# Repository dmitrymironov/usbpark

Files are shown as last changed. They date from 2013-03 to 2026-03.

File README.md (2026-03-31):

# USBPark / Parktronic

Legacy USB parking-assist software + PCB design files for a real shipped product.

This project was originally a commercial product sold to **a few hundred customers**.  
It is now released publicly to support existing customer installations, maintenance, and long-term serviceability.

Initial project funding was provided by Petroff Air, a luxury business-jet operator, which sought customization and updates for its Q8 fleet using custom embedded car computers.

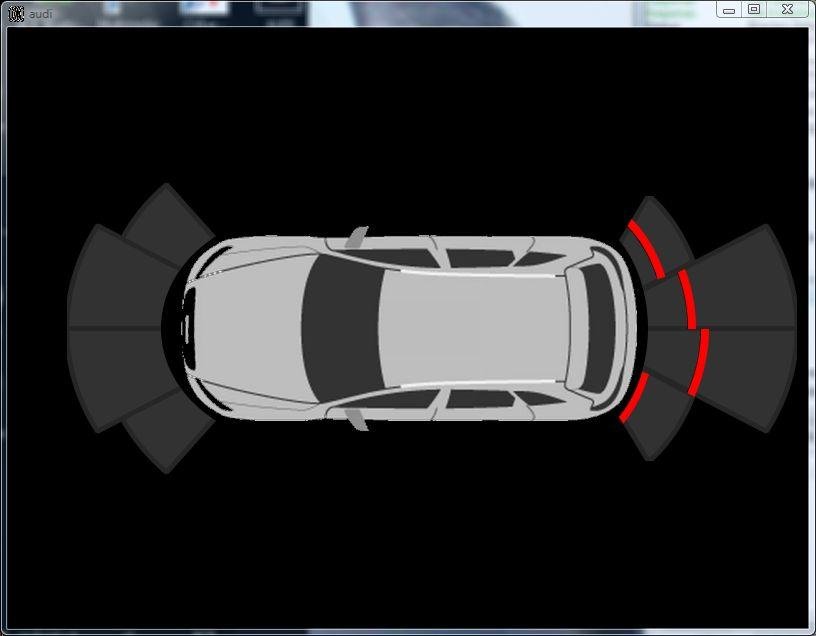
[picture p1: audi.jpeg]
USBPark demo (Audi)


## At a glance

- Desktop parking-assist software (`parktronic` and `audi`) built with Qt/C++.
- Hardware design files in Eagle format (`.sch`, `.brd`) in [`pcb/`](pcb/).
- PIC18 firmware source is included in [`firmware/`](firmware/).
- PIC18F-based controller design (PIC18F2550 appears in the v18 schematic/board design).
- Firmware update flow is integrated in the desktop app stack.

## Hardware

The latest schematic preview is included below:

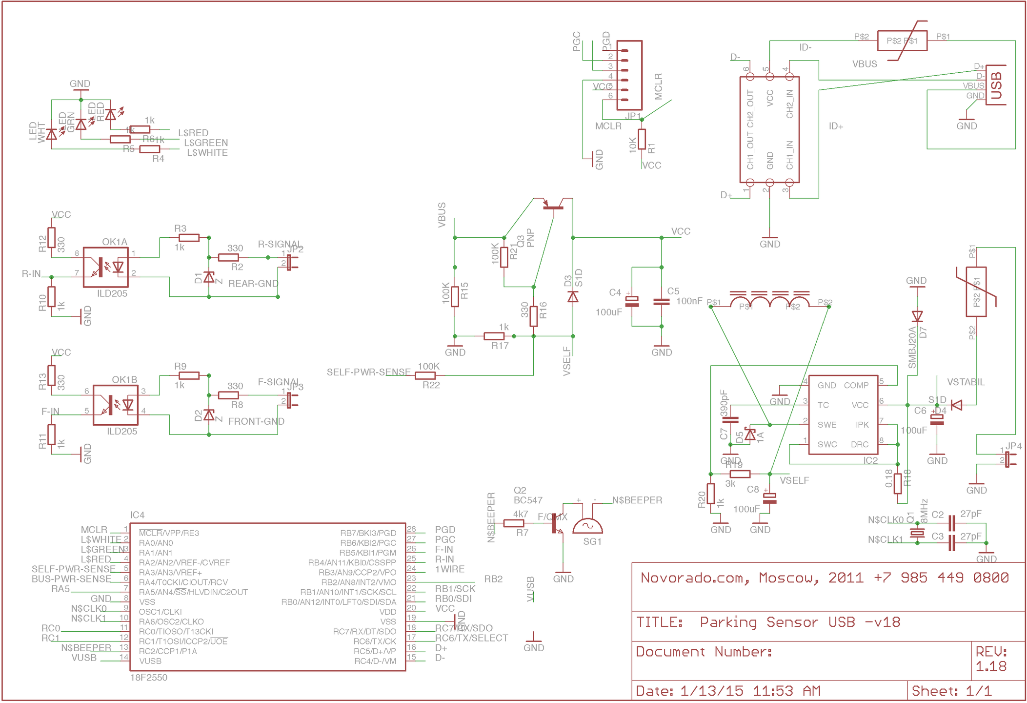
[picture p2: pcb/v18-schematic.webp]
Parking Sensor USB v18 schematic


Available PCB design assets:

- `pcb/Parking Sensor USB -v18.sch`
- `pcb/Parking Sensor USB -v18.brd`
- `pcb/Parking Sensor USB -v17b.sch`
- `pcb/Parking Sensor USB -v17b.brd`
- `pcb/v18-schematic.webp`

## Production and DIY artifacts

These files capture both ends of the hardware lifecycle: final production output and practical home-lab support tooling.

<table>
  <tr>
    <td align="center" width="50%">
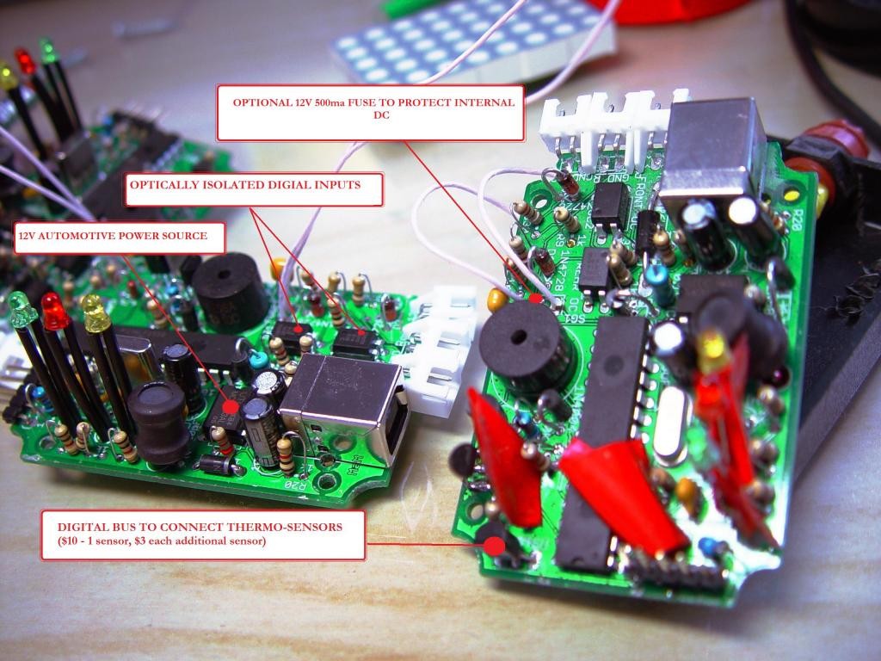
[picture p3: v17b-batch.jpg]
v17b production PCB batch
      
      <br />
      <em>v17b production batch: last commercially manufactured board run.</em>
    </td>
    <td align="center" width="50%">
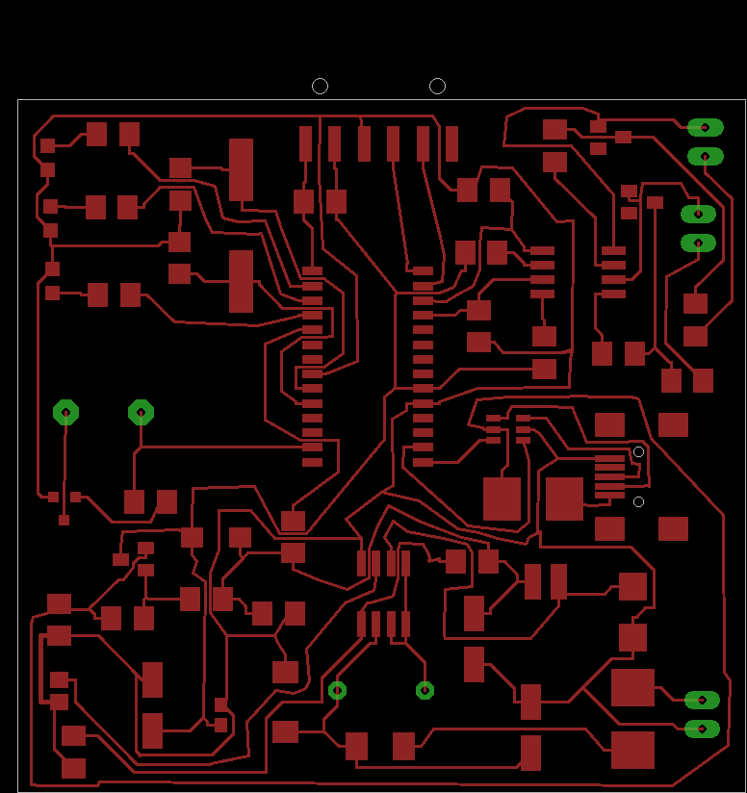
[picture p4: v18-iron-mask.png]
v18 iron mask for DIY single-metal PCB
      
      <br />
      <em>v18 iron mask: single-metal DIY transfer mask for home ironing workflow.</em>
    </td>
  </tr>
</table>

## Software components

### `parktronic/`

Main desktop application and diagnostics/configuration UI.

- Qt project: `parktronic/parktronic.pro`
- GUI tabs for diagnostics, firmware update, sounds, webcam, and settings
- Firmware resources referenced by the build (`hex/firmware.qrc`)
- Platform-specific entry points (`linux.cpp`, `win32.cpp`)

### `audi/`

Alternate/variant desktop UI package for the same product family.

- Qt project: `audi/audi.pro`
- Vehicle-oriented UI assets and sound notifications

### `firmware/`

PIC18 USB firmware source for the controller device.

- Main firmware entrypoint: `firmware/main.c`
- USB stack integration: `firmware/usb_device.c`, `firmware/usb_function_generic.c`, `firmware/usb_descriptors.c`, `firmware/usb_config.h`
- Version metadata: `firmware/version.h` (`VERSION_STRING "2.0.3"`)
- Linker scripts for PIC18F2550 variants:
  - `firmware/18F2550_NO_BOOTLOADER.lkr`
  - `firmware/rm18f2550_HID_Bootload.lkr`
- Protocol/sensor support files include I2C and DS1820 helpers plus line-decoding logic (`challenger26.*`, `i2c.*`, `ds1820.h`)

## PIC18F firmware context

This project includes a PIC18F USB-controller hardware design and host-side firmware update integration:

- Schematic/board reference to PIC18F2550 in `pcb/Parking Sensor USB -v18.sch` and `.brd`
- Host software contains firmware version/update handling paths
- Firmware source tree now included directly under `firmware/`
- Firmware code references legacy Microchip USB stack/C18 toolchain headers and bootloader settings (`../Bootloader/src/settings.h`)

## Build notes (legacy)

This is a legacy codebase (Qt4-era project files and platform-specific dependencies).

Typical flow:

```bash
cd parktronic
qmake parktronic.pro
make
```

and similarly for:

```bash
cd audi
qmake audi.pro
make
```

Notes:

- The original environment references external/internal Novorado libraries and SDK paths.
- You may need to adapt include/library paths before successful local builds.
- Firmware sources are legacy PIC18/Microchip C18-era code and may require restoring the original Microchip USB stack layout/toolchain paths to build as-is.

## Why this repo is public

The code and hardware design are published to keep deployed units supportable for existing users:

- preserve serviceability
- enable repairs and compatibility work
- allow community maintenance of legacy installations

## Repository layout

```text
usbpark-code/
├── audi/         # Variant desktop app (Qt/C++)
├── firmware/     # PIC18F2550 USB firmware source
├── parktronic/   # Main desktop app + diagnostics + firmware update UI
├── pcb/          # Eagle schematic/board files + schematic image
├── v17b-batch.jpg
├── v18-iron-mask.png
└── audi.jpeg     # Demo product image
```

## License and reuse

- `pcb/LICENSE` currently contains an MIT license text for PCB artifacts.
- Project history: originally commercial; now made public to support the installed base.
- If you need strict legal classification for reuse (public domain vs MIT-only subsets), document it explicitly for your distribution before shipping derivatives.

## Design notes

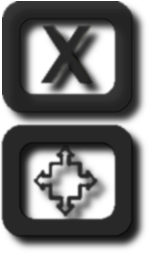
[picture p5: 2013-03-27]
audi/images/bsdark.png

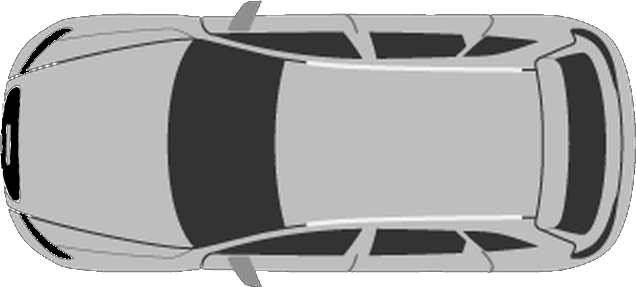
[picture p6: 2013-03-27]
audi/images/audi.png

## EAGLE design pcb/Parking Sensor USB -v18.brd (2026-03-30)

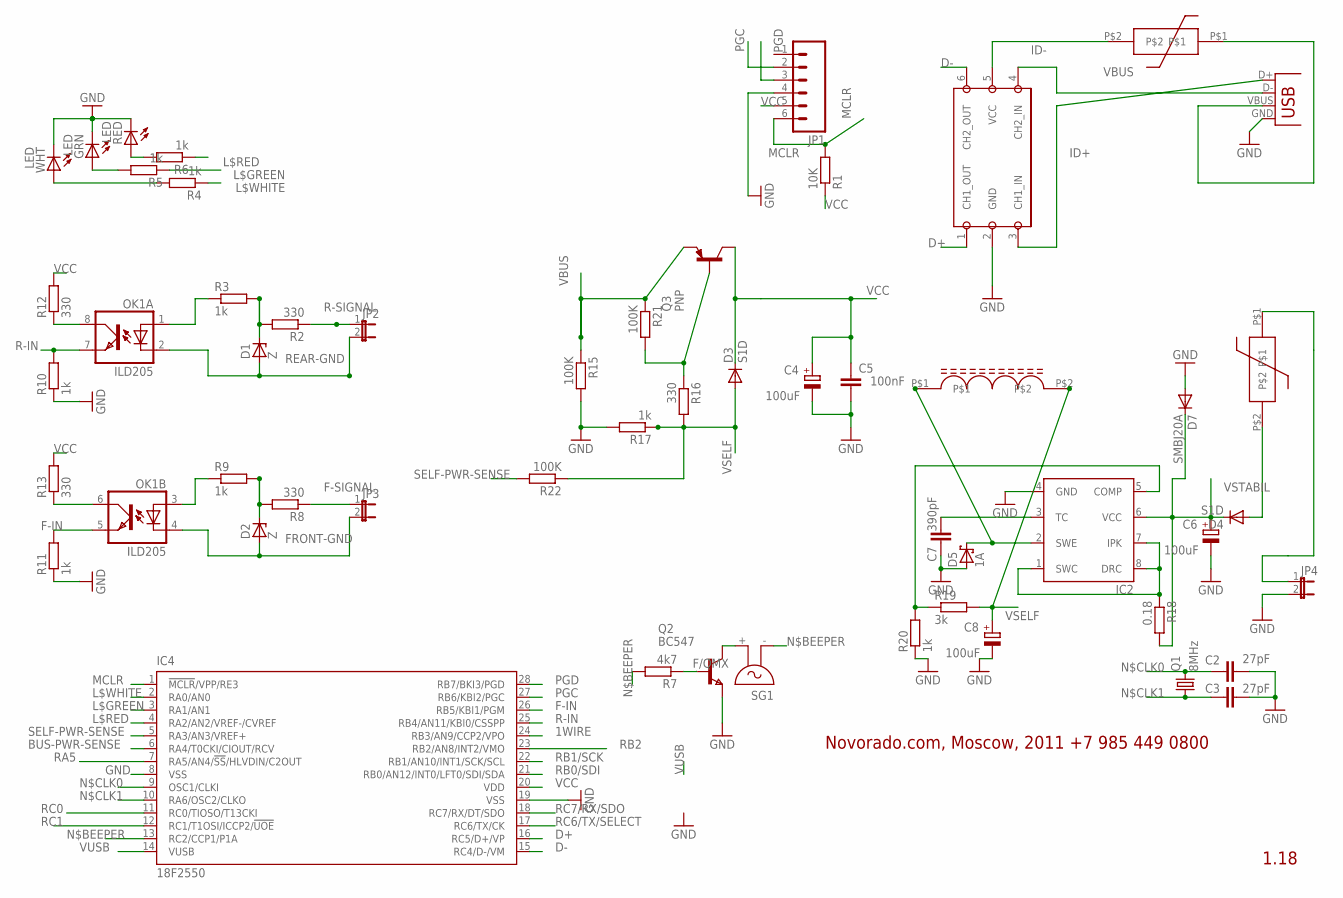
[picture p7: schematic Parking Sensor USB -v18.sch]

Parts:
C2, C3: 27pF; C1206
C4, C6, C8: 100uF; 153CLV-0505
C5: 100nF; C0603
C7: 390pF; C0805
D1, D2: Z; SOT23
D3: S1D; DO214AC
D4: S1D; DO-214AC
D5: 1A; SMB
D7: SMBJ20A; DO214AA
GRN: LED; CHIPLED_0805
IC2: MC34063AD; SO08
IC4: 18F2550; SO28W; MPN PIC18F2550-I/SO
JP1: M06SMD; 1X06-SMD
JP2, JP3, JP4: JP1E; JP1
OK1: ILD205; SOIC08
Q1: 8MHz; HC49UP
Q2: BC547; SOT-23
Q3: PNP; SOT23-BEC
R1: 10K; M1206
R2, R8, R12, R13, R16: 330; M1206
R3, R4, R5, R6, R9, R10, R11, R17, R20: 1k; M1206
R7: 4k7; M1206
R15, R21, R22: 100K; M1206
R18: 0.18; 0204/7
R19: 3k; M1206
RED: LED; CHIPLED_0805
SG1: F/QMX
U$1: EMI; SOT23-DBV
U$2, U$3: MF-SM050; SMD2029
U$5: SDR0302
WHT: LED; CHIP-LED0805
X2: USBSMD; USB-MINIB

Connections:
1WIRE: IC4.24 (RB3/AN9/CCP2/VPO)
BUS-PWR-SENSE: IC4.6 (RA4/T0CKI/CIOUT/RCV)
D+: IC4.16 (RC5/D+/VP), U$1.1 (CH1_OUT)
D-: IC4.15 (RC4/D-/VM), U$1.6 (CH2_OUT)
F-IN: IC4.26 (RB5/KBI1/PGM), OK1.5 (EMIT), R11.2
F-SIGNAL: JP3.1, R8.1
FRONT-GND: D2.1 (A), JP3.2, OK1.4 (C)
FUSE_USB: U$2.P$1, X2.VBUS
GND: C2.2, C3.2, C4.-, C5.2, C6.-, C7.1, C8.-, D5.A, D7.A, GRN.C, IC2.4 (GND), IC4.8 (VSS), IC4.19 (VSS), JP1.4, JP4.2, Q2.2 (E), R10.1, R11.1, R15.2, R17.2, R20.1, RED.C, U$1.2 (GND), WHT.C, X2.GND
ID+: U$1.3 (CH1_IN), X2.D+
ID-: U$1.4 (CH2_IN), X2.D-
L$16: GRN.A, R5.2
L$18: R6.2, RED.A
L$20: R4.2, WHT.A
L$GREEN: IC4.3 (RA1/AN1), R5.1
L$RED: IC4.4 (RA2/AN2/VREF-/CVREF), R6.1
L$WHITE: IC4.2 (RA0/AN0), R4.1
MCLR: IC4.1 (!MCLR!/VPP/RE3), JP1.6, R1.2
unnamed: Q2.3 (B), R7.1
unnamed: Q2.1 (C), SG1.+ (2)
unnamed: Q3.B, R16.1, R21.2
N$BEEPER: IC4.13 (RC2/CCP1/P1A), R7.2, SG1.- (1)
N$CLK0: C2.1, IC4.9 (OSC1/CLKI), Q1.2
N$CLK1: C3.1, IC4.10 (RA6/OSC2/CLKO), Q1.1
O1$1: OK1.1 (A), R3.1
O1$2: OK1.3 (A), R9.1
O1$3: D2.3 (C), R8.2, R9.2
O1$4: OK1.6 (COL), R13.1
O1$7: D1.3 (C), R2.2, R3.2
O1$26: OK1.8 (COL), R12.1
PGC: IC4.27 (RB6/KBI2/PGC), JP1.2
PGD: IC4.28 (RB7/BKI3/PGD), JP1.3
R-IN: IC4.25 (RB4/AN11/KBI0/CSSPP), OK1.7 (EMIT), R10.2
R-SIGNAL: JP2.1, R2.1
RA5: IC4.7 (RA5/AN4/!SS!/HLVDIN/C2OUT)
RB0/SDI: IC4.21 (RB0/AN12/INT0/LFT0/SDI/SDA)
RB1/SCK: IC4.22 (RB1/AN10/INT1/SCK/SCL)
RB2: IC4.23 (RB2/AN8/INT2/VMO)
RC0: IC4.11 (RC0/TIOSO/T13CKI)
RC1: IC4.12 (RC1/T1OSI/ICCP2/!UOE)
RC6/TX/SELECT: IC4.17 (RC6/TX/CK)
RC7/RX/SDO: IC4.18 (RC7/RX/DT/SDO)
REAR-GND: D1.1 (A), JP2.2, OK1.2 (C)
SELF-PWR-SENSE: IC4.5 (RA3/AN3/VREF+), R22.2
V5$3: JP4.1, U$3.P$1
V5$4: D4.A, U$3.P$2
V5$8: IC2.1 (SWC), IC2.7 (IPK), IC2.8 (DRC), R18.1
V5$15: C7.2, IC2.3 (TC)
V5$17: D5.C, IC2.2 (SWE), U$5.P$1
V5$47: IC2.5 (COMP), R19.1, R20.2
VBUS: Q3.E, R15.1, R21.1, U$1.5 (VCC), U$2.P$2
VCC: C4.+, C5.1, D3.C, IC4.20 (VDD), JP1.5, Q3.C, R1.1, R12.2, R13.2
VSELF: C8.+, D3.A, R16.2, R17.1, R19.2, R22.1, U$5.P$2
VSTABIL: C6.+, D4.C, D7.C, IC2.6 (VCC), R18.2
VUSB: IC4.14 (VUSB)

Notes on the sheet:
Novorado.com, Moscow, 2011 +7 985 449 0800
1.18

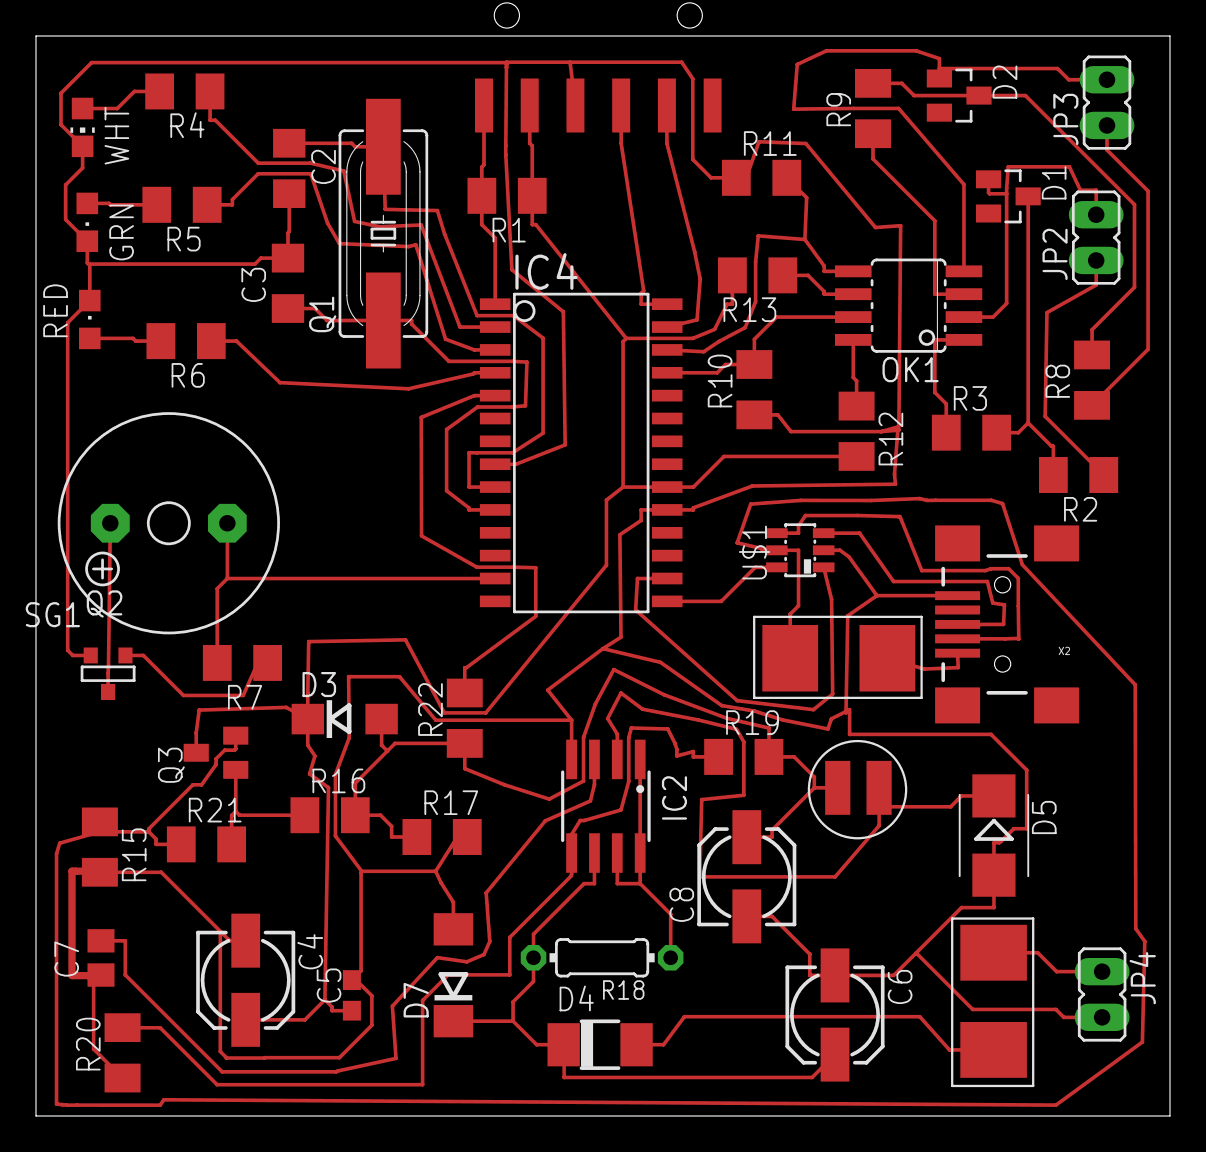
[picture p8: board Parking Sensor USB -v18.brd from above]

Board: 2 copper layers, 63.0 x 60.0 mm, 53 parts (0 on the bottom side), 44 nets.

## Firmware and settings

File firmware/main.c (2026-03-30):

// $Id: main.c,v 1.85 2012/03/26 16:36:26 dmi Exp $
/*
Causes compiler syntax error on newer USB stack 2.7
#include "Compiler.h"
#include "HardwareProfile.h"
#include "GenericTypeDefs.h"
#include "USB/usb_device.h"
#include "USB/usb.h"
#include "USB/usb_function_generic.h"
#include "usb_config.h"
*/

/*
 Timer assignment
 
 Timer0 TMR0H and TMR0L - real time clock source via "compute_clock_counter"
 Timer2 generates buzzer tone with CCP1
 Timer3 used to blink leds with "short_timeout" and "long_timeout"
 
 Timer1 is planned to be used to drive 8 additional buzzers in quadro-parkass
*/

#include "GenericTypeDefs.h"
#include "usb_config.h"
#include "USB/usb_common.h"
#include "Compiler.h"
#include "USB/usb_ch9.h"
#include "USB/usb_device.h"
#include "USB/usb_hal_pic18.h"
#include "USB/usb_function_generic.h"
#include "HardwareProfile.h"

/*
#define	set_bit(ref,b) 		((ref|=(1<<b))
#define clear_bit(ref,b)	(ref&=~(1<<b))
#define	get_bit(ref,b)		((ref&(1<<b))?1:0)
*/

#define	set_bit(ref,b) 		(ref|=(1<<b))
#define clear_bit(ref,b)	(ref&=~(1<<b))

unsigned char get_bit(unsigned char ref, unsigned char b)
{
	if(b==0) return ref & 0x1;
	return ((ref&(1<<b))?1:0);
}

#if	defined(USE_I2C)
#include "i2c.h"
#endif

#include	"../Bootloader/src/settings.h"

/* --- OLD SETTINGS

// OFF -CCP2 input/output is multiplexed with RB3
// ON - CCP2 input/output is multiplexed with RC1
#pragma config CCP2MX	= OFF
// PICEOSHIT IS BROKEN IN HARDWARE.
//

#pragma config PLLDIV   = 2         // (20 MHz crystal on PICDEM FS USB board)
#pragma config CPUDIV   = OSC1_PLL2
#pragma config USBDIV   = 2         // Clock source from 96MHz PLL/2
#pragma config FOSC     = HSPLL_HS
#pragma config FCMEN    = OFF
#pragma config IESO     = OFF
#pragma config PWRT     = OFF
#pragma config BOR      = ON
#pragma config BORV     = 3

// Disable for Self-Power 3.3v
#pragma config VREGEN   = ON      //USB Voltage Regulator

#pragma config WDT      = OFF
#pragma config WDTPS    = 32768
#pragma config LPT1OSC  = OFF

// Disable analog functions on PORTB on reset
#pragma config PBADEN   = OFF

// reset on stack overflo
#pragma config STVREN   = ON

#pragma config LVP      = OFF
//      #pragma config ICPRT    = OFF       // Dedicated In-Circuit Debug/Programming
#pragma config XINST    = OFF       // Extended Instruction Set

//
// Modifying code with bootloader can cause system erase
// Code protection
//
#pragma config MCLRE    = ON

// Code protection
#pragma config CP0      = OFF
#pragma config CP1      = OFF
#pragma config CP2      = OFF
#pragma config CP3      = OFF

// Boot block code protection
#pragma config CPB      = OFF

#pragma config WRT0     = OFF
#pragma config WRT1     = OFF
//      #pragma config WRT2     = OFF
//      #pragma config WRT3     = OFF

#pragma config WRTB     = ON       // Boot Block Write Protection
#pragma config WRTC     = OFF	   // Configuration register

//      #pragma config WRTD     = OFF
#pragma config EBTR0    = OFF
#pragma config EBTR1    = OFF
//      #pragma config EBTR2    = OFF
//      #pragma config EBTR3    = OFF
#pragma config EBTRB    = OFF
----------------------- === OLD SETTINGS === */

/** PRIVATE PROTOTYPES *********************************************/
static void InitializeSystem(void);
void USBDeviceTasks(void);
void HighPriorityInterruptHandler(void);
void LowPriorityInterruptHandler(void);
void UserInit(void);
void ProcessIO(void);
void ProcessCommands(void);

void recordDataPortSamplingInterrupt(void);
void recordPollUpdateIntoChallenger(void);
unsigned long getTimeOfLastChange(void);

void stop_interrupts(void);
void start_interrupts(void);
void timer0_stop(void);
void timer0_start(void);
void fatal_error(void);

void standalone_stop(void);
void standalone_start(void);

void poll_data_pin(void);

void pio_get_version(void);
void pio_ping(void);
#ifndef	MULTI_BUZZER
void pio_read_buzzer(void);
#endif
void pio_read_shift(void);
void pio_get_thermal(void);

unsigned char read_EEPROM(unsigned int);

void pio_reset(void);
void pio_wait_for_inhandle(void);

void ioc_start(void);
void ioc_stop(void);

#if	defined(USE_I2C)
void process_i2c_interrupt(void);
void open_i2c(void);
void close_i2c(void);
#endif

void makeStatusDataPacket(void);
void add_ch26data_bit(unsigned char);

#ifndef	MULTI_BUZZER
void setup_buzzer(void);
void buzzer_on(void);
void buzzer_off(void);
#endif

void grabMinDistance(void);

#ifndef	MULTI_BUZZER
void buzzer_distance(void);
void buzzer_wait_for_5beeps(void);
void save_buzzer(unsigned char arr[]);
#endif

void save_shift(unsigned char arr[]);

void stop_timer3(void);
void start_timer3(void);
void timer3_interrupt(void);

void short_timeout(void);
void long_timeout(void);

//void set_state(unsigned char);

#ifndef	MULTI_BUZZER
#define buzzer_status() T2CONbits.TMR2ON
#define	buzzer_3beeps() { ledS.buzzerCounter=3; }
#endif

// Counts number of cycles passed from the beginning of measurement
unsigned long sampling_clock_counter = 0;	//var

#include	"rc2sample.h"


////////////////////////////////////// CHALLANGER26 // START
#include "challenger26.h"

// Used functions prototypes
void init_BuzzDevs(void);
int set_EEPROM(unsigned int addr,unsigned char val);
void Delay100TCYx ( unsigned char unit );

unsigned char widthSilence(unsigned long l);
unsigned char widthDataTimeout(unsigned long l);
void initDistData(struct DistData*);
void initChallengerLine(struct ChallengerLine*);

unsigned char widthLow(unsigned long l);
unsigned char isNoise(unsigned long l);

int detectImpulse(unsigned long l, unsigned long h);
unsigned char writeToChallengerData(
	struct ChallengerLine* c,
	unsigned long l,
	unsigned long h);
int isValidChallengerPacket(const struct ChallengerLine* c);
void processChallengerPacket(const struct ChallengerLine* c);

// LEDS
// FSM
#define ANIMATION_ALL_3SHORT 		0x1
#define	ANIMATION_ALL_2SHORT_LONG 	0x2

void led_animate(unsigned char code);
void init_leds(void);
void led_set(char led,char status);

////////////////////////////////////// CHALLENGER26 // END
/*
	Signalling status with LEDs

	Bootloader - RED

	Power on - GREEN

	Fatal error - All LEDs long blink

	PING - YELLOW/GREEN/RED short-short-short
	VERSION - YELLOW/GREEN/RED short-short-long

	RB4 activity - RED short blink
	RB5 activity - YELLOW short blink

	FEEDING SAMPLE data - GREEN short blink
	FEEDING FORMATTED data - GREEN long blink
*/

#define	T3_PERIOD_SHORT 2
#define	T3_PERIOD_LONG  12

#define DATACOUNT_LIMIT 10
#define	DATACOUNT_STEP	3

#define	lOFF	0b00
#define	lSHORT	0b01
#define	lLONG	0b10
#define	lON	0b11

#define	LED_WHITE	0b001
#define	LED_GREEN	0b010
#define	LED_RED		0b100

#define	colorOn(b) 	_clrOn(LED_##b)
#define	colorOff(b)	_clrOff(LED_##b)

void _clrOn(unsigned char c)
{
	PORTA|=c;
}

void _clrOff(unsigned char c)
{
	PORTA&=~c;
}

struct SignalLed {
	unsigned char s: 1;
	unsigned char l: 1;
	unsigned char cnt : 4; // 0-15

	unsigned char red: 2;
	unsigned char green: 2;
	unsigned char white: 2;

	unsigned char bkRed: 2;
	unsigned char bkGreen: 2;
	unsigned char bkWhite: 2;

	#ifndef	MULTI_BUZZER
	unsigned char buzzerAlwaysOn: 1;
	unsigned char buzzerPeriod:5;
	// countdown of beeps if no buzzerPeriod set
	// countdown of delay if buzzerPeriod set
	unsigned char buzzerCounter:5;
	#endif
	
	// Finate state machine mechanism
	unsigned char animation_code: 3; // 0-7
	unsigned char animation_count: 4; // 0-15

	// That will be changed by short interrupt
	unsigned char countRB4:2;
	unsigned char countRB5:2;

	unsigned char dataCountRB4;
	unsigned char dataCountRB5;

	unsigned char minDistance;

	unsigned char usbOUTtimeout;
	} ledS;

// LEDS - end
struct Quant {
	unsigned char q_data;
	unsigned long q_time;
	};

#define	BITFLAG(a)	unsigned char a: 1;

struct _flags {
	BITFLAG(get_version)
	BITFLAG(get_thermal)
	BITFLAG(reset)
	BITFLAG(standalone)
	// stop_reading will also clear scanner state
	BITFLAG(stop_reading)
	// read_parktronic is one time command, that will initiate reading process
	BITFLAG(read_parktronic)
	// Scanner flag indicates that we are processing the
	// data without sending samples out. It's only the flag
	BITFLAG(scanner)
#if	defined(USE_I2C)
	BITFLAG(open_i2c)
	BITFLAG(close_i2c)
#endif
	BITFLAG(get_io_registers1)
	BITFLAG(get_io_registers2)
	BITFLAG(ping)
#ifndef	MULTI_BUZZER	
	BITFLAG(buzzer)
#endif	
	BITFLAG(shift)
	BITFLAG(data_packet)
	// Flag indicates no data currently arrives
	BITFLAG(no_feed)
	};

#define	BITFLAG1(a)	flags.a=1;
#define	BITFLAG0(a)	flags.a=0;

//This return will be a "retfie fast", since this is in a #pragma interrupt section
struct _flags flags;	//var
	
#ifdef	MULTI_BUZZER
void generate_carry_pwm();
void generate_carry_pwm()
{
	T2CONbits.TMR2ON=0;
	
	T2CONbits.T2CKPS1=1;
	T2CONbits.T2CKPS0=0;//TMR2 prescale: 16

	// Target for 2.5Khz carrying pwm 49:16
	PR2=255;
	
	// T2OUTPS Poscatscale 1111=1:16 0001=1:2 0000=1:1
	T2CONbits.T2OUTPS3=0;
	T2CONbits.T2OUTPS2=0;
	T2CONbits.T2OUTPS1=0;
	T2CONbits.T2OUTPS0=0;

	// 100 gives 50% duty
	
	// duty cycle control
	CCPR1L=110; 
	CCP1CONbits.DC1B0=0;
	CCP1CONbits.DC1B1=0;

	// Start CCP1, module configuration
	TRISCbits.TRISC2=0; // CCP1

	// CCPxM3:CCPxM0 11xx for PWM
	CCP1CONbits.CCP1M3=1;
	CCP1CONbits.CCP1M2=1;
	CCP1CONbits.CCP1M1=0;
	CCP1CONbits.CCP1M0=1;
	
	// Generating timer 2 on
	T2CONbits.TMR2ON=1;
}

#ifdef	MULTI_BUZZER

// 
// Datastructures for multi-buzzer support
//

// Configure pins for driving extrenal output
// RC1, RC0, RA5, RB2, RB1, RB0, RC7, RC6

// HCM1206A max loud: 2520Hz, 395us period

// 5.3KHz TMR1H=0xFA;TMR1L=0x00;
// 4.3KHz TMR1H=0xF8;TMR1L=0x00;
// 3.1KHz TMR1H=0xF4;TMR1L=0x00;
// 2.5Khz TMR1H=0xF0;TMR1L=0x00;
// 2.1Khz TMR1H=0xEE;TMR1L=0x00;
// TMR1H=0xFA;TMR1L=0x00; -- max loud for HCM1206A on 1:2
// #define	TIMER1_SET_COUNTERS TMR1H=0x80;TMR1L=0x00;

#define	TRIS0	TRISCbits.TRISC1
#define	TRIS1	TRISCbits.TRISC0
#define	TRIS2	TRISAbits.TRISA5
#define	TRIS3	TRISBbits.TRISB2
#define	TRIS4	TRISBbits.TRISB1
#define	TRIS5	TRISBbits.TRISB0
#define	TRIS6	TRISCbits.TRISC7
#define	TRIS7	TRISCbits.TRISC6

/* Debug times only
#define	PIN0	PORTCbits.RC1
#define	PIN1	PORTCbits.RC0
#define	PIN2	PORTAbits.RA5
#define	PIN3	PORTBbits.RB2
#define	PIN4	PORTBbits.RB1
#define	PIN5	PORTBbits.RB0
#define	PIN6	PORTCbits.RC7
#define	PIN7	PORTCbits.RC6
*/
#define	ADDR_PORTC	((unsigned char*)(0xF82))
#define	ADDR_PORTB	((unsigned char*)(0xF81))
#define	ADDR_PORTA	((unsigned char*)(0xF80))
struct BuzzDev {

	//
	// SOUND GENERATION PART
	//

	unsigned char* portAddr;
	unsigned char bitA;
	unsigned char rBitA;
	
	//
	// DISTANCE TIMER
	//
			
	unsigned int pause; // How many clocks pass between beeps	
	unsigned int cycles;	
	//
	unsigned char id;
	unsigned char prevDist;
	} buzzdevs[] = {
		/* Second parameter must be 2x to first: widht = load*2 for 50% PWM */
		//////////////////////////////////////////////////////////////////////
		{ADDR_PORTC,0b10,0},  // RC1
		{ADDR_PORTC,0b1,0},	// RC0
		{ADDR_PORTA,0b100000,0},	// RA5
		{ADDR_PORTB,0b100,0},	// RB2
		{ADDR_PORTB,0b10,0},	// RB1
		{ADDR_PORTB,0b1,0},	// RB0
		{ADDR_PORTC,0b10000000,0},	// RC7
		{ADDR_PORTC,0b1000000,0},	// RC6
		{NULL,0,0}
		};

#define	signalBD(d)	(*d->portAddr&d->bitA)
#define	highBD(d)	*d->portAddr|=d->bitA
#define	lowBD(d)	*d->portAddr&=d->rBitA

void start_timer1(void);
void stop_timer1(void);
#endif

// Number of cycles in the beep
#define	BEEP_DURATION	2
struct BuzzDev* shortListBD[9]={NULL,NULL,NULL,NULL,NULL,NULL,NULL,NULL,NULL};

void setBuzzDevDistance(unsigned char id, unsigned char dist)
{
	int idx=0;
	struct BuzzDev* d = &buzzdevs[id];
	// If distance has not changed, go on
	if(d->prevDist==dist) return;
	d->prevDist=dist;
	
	if(dist<30) {	
		// Turn buzzer on
		highBD(d);
		// Disengage all timer-based beeping
		d->cycles=0;
		d->pause=0;		
	}
	else if(dist<26) { d->pause=1; }
	else if(dist<35) { d->pause=2; }
	else if(dist<45) { d->pause=3; }
	else if(dist<55) { d->pause=5; }
	else if(dist<65) { d->pause=7; }
	else if(dist<75) { d->pause=10; }
	else if(dist<85) { d->pause=12; }
	else if(dist<100) { d->pause=14; }
	else if(dist<120) { d->pause=18; }
	else if(dist<140) { d->pause=24; }
	else if(dist<160) { d->pause=26; }
	else if(dist<180) { d->pause=30; }
	else if(dist<200) { d->pause=40; }
	else {
		lowBD(d);
		d->pause=0;
		}
	
	// Re-compute short list of buzzers
	for(d=buzzdevs,idx=0; d->portAddr!=NULL; d++) {
		shortListBD[idx]=NULL;
		if(d->pause) {
			shortListBD[idx++]=d;
			shortListBD[idx]=NULL;
			}
		}
		
	if(idx) start_timer1(); else stop_timer1();
}

void init_BuzzDevs()
{
	unsigned char i=0;
	struct BuzzDev* d=buzzdevs;

	// Make outputs from pins
	TRIS0=0;
	TRIS1=0;
	TRIS2=0;
	TRIS3=0;
	TRIS4=0;
	TRIS5=0;
	TRIS6=0;
	TRIS7=0;
	
	for(i=0;d->portAddr!=NULL;d++,i++) {
		d->id=i;
		d->rBitA=~d->bitA;
		// initialize pin to logic zero to avoid leakage
		lowBD(d);
		d->pause=0;
		d->cycles=0;
		d->prevDist=0;
		}
}
#endif // MULTI_BUZZER

//
// Size of that structure must be 64 bytes,
// or less.
//
struct RC2MeasurementUSB {

	// Number of impulses it holds (instead of 0-terminated array)
	unsigned char code;//COMMAND_READ_DATA_PACKET
	unsigned char size;
	struct Quant deckCycles[USB_PACKET_SIZE];

	unsigned char uData[2];
};

union _m_send2host {
	// Raw data
	char _version_buf[64];
	// Raw sampling data
	struct RC2MeasurementUSB _usbStat;
	};

struct RC2Measurement {
	// Counters
	struct Quant deckCycles[STORAGE_PACKET_SIZE];
};

#pragma code

union clkdata {
	struct s2byte {
		unsigned char b0, b1;
		} s2byte;
	unsigned short clk_count;
	};

#define	compute_clock_counter()	\
	timer_clkdata.s2byte.b1=TMR0H;	\
	timer_clkdata.s2byte.b0=TMR0L;	\
	sampling_clock_counter += (timer_clkdata.clk_count-timer_prev_clk_count);	\
	timer_prev_clk_count=timer_clkdata.clk_count;

// How many parktronic interfaces can stick up on the controller
// RB7, RB6, RB5, RB4
#define	NUMBER_OF_CHALLENGER_DEVICES	2
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
void main(void)
{
	InitializeSystem();

	#if defined(USB_INTERRUPT)
	USBDeviceAttach();
	#endif

	while(1)
	{
		// Check bus status and service USB interrupts.
		USBDeviceTasks(); // Interrupt or polling method.  If using polling, must call
			  // this function periodically.  This function will take care
			  // of processing and responding to SETUP transactions
			  // (such as during the enumeration process when you first
			  // plug in).  USB hosts require that USB devices should accept
			  // and process SETUP packets in a timely fashion.  Therefore,
			  // when using polling, this function should be called
			  // frequently (such as once about every 100 microseconds) at any
			  // time that a SETUP packet might reasonably be expected to
			  // be sent by the host to your device.  In most cases, the
			  // USBDeviceTasks() function does not take very long to
			  // execute (~50 instruction cycles) before it returns.

		// Application-specific tasks.
		// Application related code may be added here, or in the ProcessIO() function.
		ProcessIO();

		//
		// It will process commands one at time accordingly to flags
		//
		ProcessCommands();

	}//end while

	stop_timer3();

}//end main

// ******************************************************************************************************
// ************** USB Callback Functions ****************************************************************
// ******************************************************************************************************
// The USB firmware stack will call the callback functions USBCBxxx() in response to certain USB related
// events.  For example, if the host PC is powering down, it will stop sending out Start of Frame (SOF)
// packets to your device.  In response to this, all USB devices are supposed to decrease their power
// consumption from the USB Vbus to <2.5mA each.  The USB module detects this condition (which according
// to the USB specifications is 3+ms of no bus activity/SOF packets) and then calls the USBCBSuspend()
// function.  You should modify these callback functions to take appropriate actions for each of these
// conditions.  For example, in the USBCBSuspend(), you may wish to add code that will decrease power
// consumption from Vbus to <2.5mA (such as by clock switching, turning off LEDs, putting the
// microcontroller to sleep, etc.).  Then, in the USBCBWakeFromSuspend() function, you may then wish to
// add code that undoes the power saving things done in the USBCBSuspend() function.

// The USBCBSendResume() function is special, in that the USB stack will not automatically call this
// function.  This function is meant to be called from the application firmware instead.  See the
// additional comments near the function.

/******************************************************************************
 * Function:        void USBCBSuspend(void)
 *
 * PreCondition:    None
 *
 * Input:           None
 *
 * Output:          None
 *
 * Side Effects:    None
 *
 * Overview:        Call back that is invoked when a USB suspend is detected
 *
 * Note:            None
 *****************************************************************************/

void ConfigureIOPinsForLowPower()
{
	// Stop all related interrupts
	stop_interrupts();
	stop_timer3();

	// Turn off the buzzer
	standalone_stop();

	// Hide leds
	TRISA=0x0; Nop();Nop();Nop(); PORTA=0x0;
}

void SaveStateOfAllInterruptEnableBits()
{
}

void DisableAllInterruptEnableBits()
{
}

void EnableOnlyTheInterruptsWhichWillBeUsedToWakeTheMicro()
{
	PIR2bits.USBIF=0;
	PIE2bits.USBIE=1;
	UIEbits.ACTVIE=1;
	UIRbits.ACTVIF=1;
}

void RestoreStateOfAllPreviouslySavedInterruptEnableBits()
{
}

void RestoreIOPinsToNormal()
{
	// Just reset all the user functions and set thing to standalone mode
	UserInit();
}

void USBCBSuspend(void)
{
/*
	//Example power saving code.  Insert appropriate code here for the desired
	//application behavior.  If the microcontroller will be put to sleep, a
	//process similar to that shown below may be used:

	ConfigureIOPinsForLowPower();
	SaveStateOfAllInterruptEnableBits();
	DisableAllInterruptEnableBits();
	EnableOnlyTheInterruptsWhichWillBeUsedToWakeTheMicro();	//should enable at least USBActivityIF as a wake source
	Sleep();
	//RestoreStateOfAllPreviouslySavedInterruptEnableBits();	//Preferrably, this should be done in the USBCBWakeFromSuspend() function instead.
	//RestoreIOPinsToNormal();	//Preferrably, this should be done in the USBCBWakeFromSuspend() function instead.

	//IMPORTANT NOTE: Do not clear the USBActivityIF (ACTVIF) bit here.  This bit is
	//cleared inside the usb_device.c file.  Clearing USBActivityIF here will cause
	//things to not work as intended.
*/
}


/******************************************************************************
 * Function:        void _USB1Interrupt(void)
 *
 * PreCondition:    None
 *
 * Input:           None
 *
 * Output:          None
 *
 * Side Effects:    None
 *
 * Overview:        This function is called when the USB interrupt bit is set
 *					In this example the interrupt is only used when the device
 *					goes to sleep when it receives a USB suspend command
 *
 * Note:            None
 *****************************************************************************/
#if 0
void __attribute__ ((interrupt)) _USB1Interrupt(void)
{
    #if !defined(self_powered)
        if(U1OTGIRbits.ACTVIF)
        {
            IEC5bits.USB1IE = 0;
            U1OTGIEbits.ACTVIE = 0;
            IFS5bits.USB1IF = 0;

            //USBClearInterruptFlag(USBActivityIFReg,USBActivityIFBitNum);
            USBClearInterruptFlag(USBIdleIFReg,USBIdleIFBitNum);
            //USBSuspendControl = 0;
        }
    #endif
}
#endif

/******************************************************************************
 * Function:        void USBCBWakeFromSuspend(void)
 *
 * PreCondition:    None
 *
 * Input:           None
 *
 * Output:          None
 *
 * Side Effects:    None
 *
 * Overview:        The host may put USB peripheral devices in low power
 *					suspend mode (by "sending" 3+ms of idle).  Once in suspend
 *					mode, the host may wake the device back up by sending non-
 *					idle state signalling.
 *
 *					This call back is invoked when a wakeup from USB suspend
 *					is detected.
 *
 * Note:            None
 *****************************************************************************/
void USBCBWakeFromSuspend(void)
{
	// If clock switching or other power savings measures were taken when
	// executing the USBCBSuspend() function, now would be a good time to
	// switch back to normal full power run mode conditions.  The host allows
	// a few milliseconds of wakeup time, after which the device must be
	// fully back to normal, and capable of receiving and processing USB
	// packets.  In order to do this, the USB module must receive proper
	// clocking (IE: 48MHz clock must be available to SIE for full speed USB
	// operation).

/*
	RestoreStateOfAllPreviouslySavedInterruptEnableBits();	//Preferrably, this should be done in the USBCBWakeFromSuspend() function instead.
	RestoreIOPinsToNormal();	//Preferrably, this should be done in the USBCBWakeFromSuspend() function instead.
*/
}

/********************************************************************
 * Function:        void USBCB_SOF_Handler(void)
 *
 * PreCondition:    None
 *
 * Input:           None
 *
 * Output:          None
 *
 * Side Effects:    None
 *
 * Overview:        The USB host sends out a SOF packet to full-speed
 *                  devices every 1 ms. This interrupt may be useful
 *                  for isochronous pipes. End designers should
 *                  implement callback routine as necessary.
 *
 * Note:            None
 *******************************************************************/
void USBCB_SOF_Handler(void)
{
    // No need to clear UIRbits.SOFIF to 0 here.
    // Callback caller is already doing that.
}
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

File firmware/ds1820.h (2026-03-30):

   /*** FILEHEADER ****************************************************************
 *
 *    FILENAME:    ds1820.h
 *    DATE:        25.02.2005
 *    AUTHOR:      Christian Stadler
 *
 *    DESCRIPTION: Driver for DS1820 1-Wire Temperature sensor (Dallas)
 *
 ******************************************************************************/

/*** HISTORY OF CHANGE *********************************************************
 *
 *    $Log: /pic/_drv/ds1820.h $
 * 
 * 9     13.11.10 20:02 Stadler
 * - changed interrupt lock and delay functions to #defines to remove
 * function call overhead
 * 
 * 8     6.11.10 10:24 Stadler
 * - adjusted 1-wire timing
 * 
 * 7     5.11.10 22:55 Stadler
 * - changed driver API
 * 
 * 6     5.11.10 21:59 Stadler
 * - added DS18B20 support
 * - fixed problem with ROM search algorithm
 * 
 * 5     2.11.10 20:25 Stadler
 * - changed function DS1820_FindFirstDev to DS1820_FindFirstDevice
 * - changed function DS1820_FindNextDev to DS1820_FindNextDevice
 * - updated code style
 * 
 * 4     31.10.10 17:12 Stadler
 * - introduced DS1820_DelayUs
 * 
 * 3     25.10.10 13:09 Stadler
 * - added interrupt lock
 * 
 * 2     12.03.05 11:24 Stadler
 * - added EEPROM write function
 * - added "Search ROM Algorithm" to control multiple devices
 *
 * 1     26.02.05 18:18 Stadler
 * Driver for DS1820 1-Wire Temperature sensor (Dallas)
 *
 ******************************************************************************/

#ifndef _DS1820_H
#define _DS1820_H


/* check configuration of driver */
#ifndef DS1820_DATAPIN
#error DS1820 data pin not defined!
#endif


#define TEMP_RES              0x100 /* temperature resolution => 1/256°C = 0.0039°C */


/* -------------------------------------------------------------------------- */
/*                         DS1820 Timing Parameters                           */
/* -------------------------------------------------------------------------- */

#define DS1820_RST_PULSE       480   /* master reset pulse time in [us] */
#define DS1820_MSTR_BITSTART   2     /* delay time for bit start by master */
#define DS1820_PRESENCE_WAIT   40    /* delay after master reset pulse in [us] */
#define DS1820_PRESENCE_FIN    480   /* dealy after reading of presence pulse [us] */
#define DS1820_BITREAD_DLY     5     /* bit read delay */
#define DS1820_BITWRITE_DLY    100   /* bit write delay */


/* -------------------------------------------------------------------------- */
/*                            DS1820 Registers                                */
/* -------------------------------------------------------------------------- */

#define DS1820_REG_TEMPLSB    0
#define DS1820_REG_TEMPMSB    1
#define DS1820_REG_CNTREMAIN  6
#define DS1820_REG_CNTPERSEC  7
#define DS1820_SCRPADMEM_LEN  9     /* length of scratchpad memory */

#define DS1820_ADDR_LEN       8


/* -------------------------------------------------------------------------- */
/*                            DS1820 Commands                                 */
/* -------------------------------------------------------------------------- */

#define DS1820_CMD_SEARCHROM     0xF0
#define DS1820_CMD_READROM       0x33
#define DS1820_CMD_MATCHROM      0x55
#define DS1820_CMD_SKIPROM       0xCC
#define DS1820_CMD_ALARMSEARCH   0xEC
#define DS1820_CMD_CONVERTTEMP   0x44
#define DS1820_CMD_WRITESCRPAD   0x4E
#define DS1820_CMD_READSCRPAD    0xBE
#define DS1820_CMD_COPYSCRPAD    0x48
#define DS1820_CMD_RECALLEE      0xB8


#define DS1820_FAMILY_CODE_DS18B20      0x28
#define DS1820_FAMILY_CODE_DS18S20      0x10


/* -------------------------------------------------------------------------- */
/*                            static variables                                */
/* -------------------------------------------------------------------------- */

static bool bDoneFlag;
static uint8 nLastDiscrepancy_u8;
static uint8 nRomAddr_au8[DS1820_ADDR_LEN];



/* -------------------------------------------------------------------------- */
/*                           Low-Level Functions                              */
/* -------------------------------------------------------------------------- */

/*******************************************************************************
 * FUNCTION:   DS1820_DelayUs
 * PURPOSE:    Delay for the given number of micro seconds.
 *
 * INPUT:      dly_us      number of micro seconds to delay
 * OUTPUT:     -
 * RETURN:     -
 ******************************************************************************/
#define DS1820_DelayUs(dly_us)       delay_us(dly_us)


/*******************************************************************************
 * FUNCTION:   DS1820_DelayMs
 * PURPOSE:    Delay for the given number of milliseconds.
 *
 * INPUT:      dly_ms      number of milliseconds to delay
 * OUTPUT:     -
 * RETURN:     -
 ******************************************************************************/
#define DS1820_DelayMs(dly_ms)   delay_ms(dly_ms)


/*******************************************************************************
 * FUNCTION:   DS1820_DisableInterrupts
 * PURPOSE:    Disable interrupts
 *
 * INPUT:      -
 * OUTPUT:     -
 * RETURN:     -
 ******************************************************************************/
#ifdef DS1820_INTERRUPT_LOCK
#define DS1820_DisableInterrupts()  INTCONbits.GIEH=0;INTCONbits.GIEL=0;
#else
#define DS1820_DisableInterrupts()
#endif

/*******************************************************************************
 * FUNCTION:   DS1820_EnableInterrupts
 * PURPOSE:    Enable interrupts
 *
 * INPUT:      -
 * OUTPUT:     -
 * RETURN:     -
 ******************************************************************************/
#ifdef DS1820_INTERRUPT_LOCK
#define DS1820_EnableInterrupts()   INTCONbits.GIEH=1;INTCONbits.GIEL=1;
#else
#define DS1820_EnableInterrupts()
#endif


/*******************************************************************************
 * FUNCTION:   DS1820_Reset
 * PURPOSE:    Initializes the DS1820 device.
 *
 * INPUT:      -
 * OUTPUT:     -
 * RETURN:     FALSE if at least one device is on the 1-wire bus, TRUE otherwise
 ******************************************************************************/
bool DS1820_Reset(void)
{
   bool bPresPulse;

   DS1820_DisableInterrupts();
   
   /* reset pulse */
   output_low(DS1820_DATAPIN);
   DS1820_DelayUs(DS1820_RST_PULSE);
   output_high(DS1820_DATAPIN);

   /* wait until pullup pull 1-wire bus to high */
   DS1820_DelayUs(DS1820_PRESENCE_WAIT);

   /* get presence pulse */
   bPresPulse = input(DS1820_DATAPIN);

   DS1820_DelayUs(424);
   
   DS1820_EnableInterrupts();

   return bPresPulse;
}
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

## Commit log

2026-03-30 Adding Eagle Board and Schematic
    [Parking Sensor USB -v17b.brd, Parking Sensor USB -v17b.sch, Parking Sensor USB -v18.brd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]
2026-03-31 Adding last production batch PCBs

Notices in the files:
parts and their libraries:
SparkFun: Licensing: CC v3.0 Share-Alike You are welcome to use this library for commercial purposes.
